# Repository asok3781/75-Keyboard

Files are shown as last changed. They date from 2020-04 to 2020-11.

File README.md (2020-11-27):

# Asok75
A 75% keyboard PCB.

A simple [acrylic case](Case) has also been designed - .dxf files are in the Case folder in the repository.

This PCB is designed to work with [QMK firmware](https://github.com/asok3781/qmk_firmware/tree/asok/keyboards/asok/asok75) (firmware is in my branch of the QMK firmware in the expected location).

A [VIA definition](asok75VIAdefinition) has also been created to be able to customise the layout of the keyboard easily.

Picture of the keyboard that I designed

Another angle

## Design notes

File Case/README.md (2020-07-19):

# Asok75 Case
A simple acrylic sandwich case for the pcb.
Layer thicknesses:
top.dxf - 3mm
tophex.dxf - 4.5mm
plate.dxf - 5mm
mid.dxf - 3mm x 2
bottom.dxf - 3mm
foot1.dxf - 3mm
foot2.dxf - 3mm
foot3.dxf - 3mm
foot4.dxf - 3mm

Use 15-16mm length and 8-9mm length, 5mm flat to flat hex standoffs and M3 screws.

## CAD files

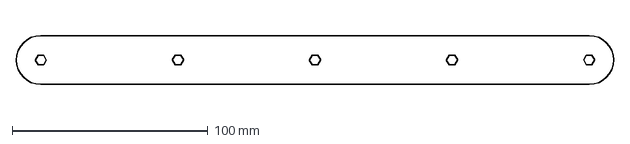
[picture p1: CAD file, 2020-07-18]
Case/foot1.dxf
305.0 x 25.0 mm

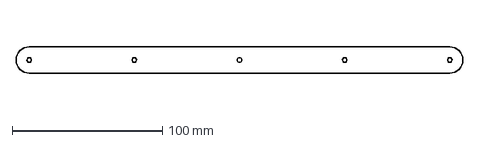
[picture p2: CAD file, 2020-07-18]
v1-pcb/Case/foot4.dxf
297.5 x 17.5 mm

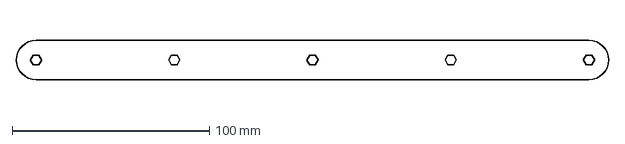
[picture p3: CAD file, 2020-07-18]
Case/foot3.dxf
300.0 x 20.0 mm

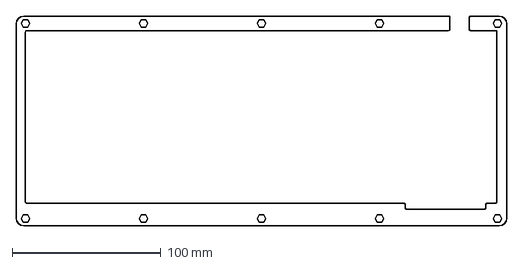
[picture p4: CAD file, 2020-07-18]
v1-pcb/Case/mid.dxf
330.0 x 141.0 mm

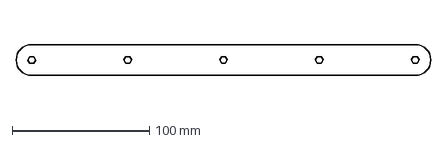
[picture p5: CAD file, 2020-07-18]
Case/foot2.dxf
302.5 x 22.5 mm

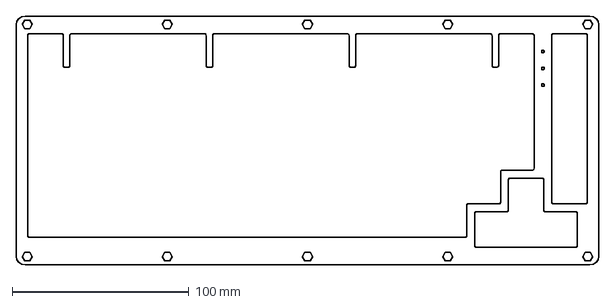
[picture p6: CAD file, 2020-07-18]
Case/tophex.dxf
330.0 x 141.0 mm

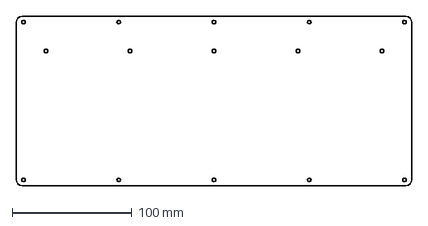
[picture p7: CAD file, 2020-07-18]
Case/bottom.dxf
330.0 x 141.0 mm

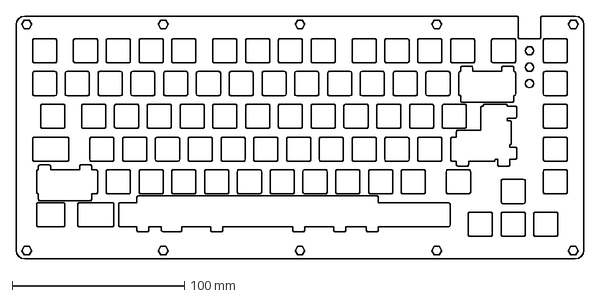
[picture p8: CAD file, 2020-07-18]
v1-pcb/Case/plate.dxf
330.0 x 141.0 mm

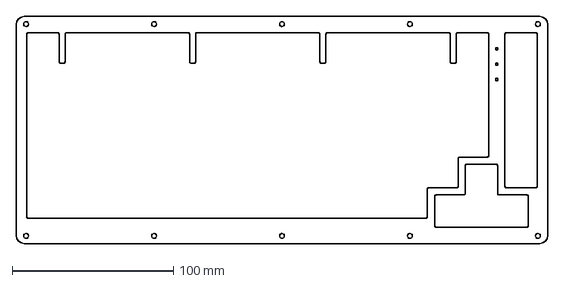
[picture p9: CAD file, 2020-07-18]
v1-pcb/Case/top.dxf
330.0 x 141.0 mm

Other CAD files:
Case/foot-0.dxf
Case/foot-1.dxf
Case/foot-2.dxf
Case/foot-3.dxf
Case/foot-4.dxf
Case/midclose.dxf
Case/midclosed.dxf
Case/topround.dxf

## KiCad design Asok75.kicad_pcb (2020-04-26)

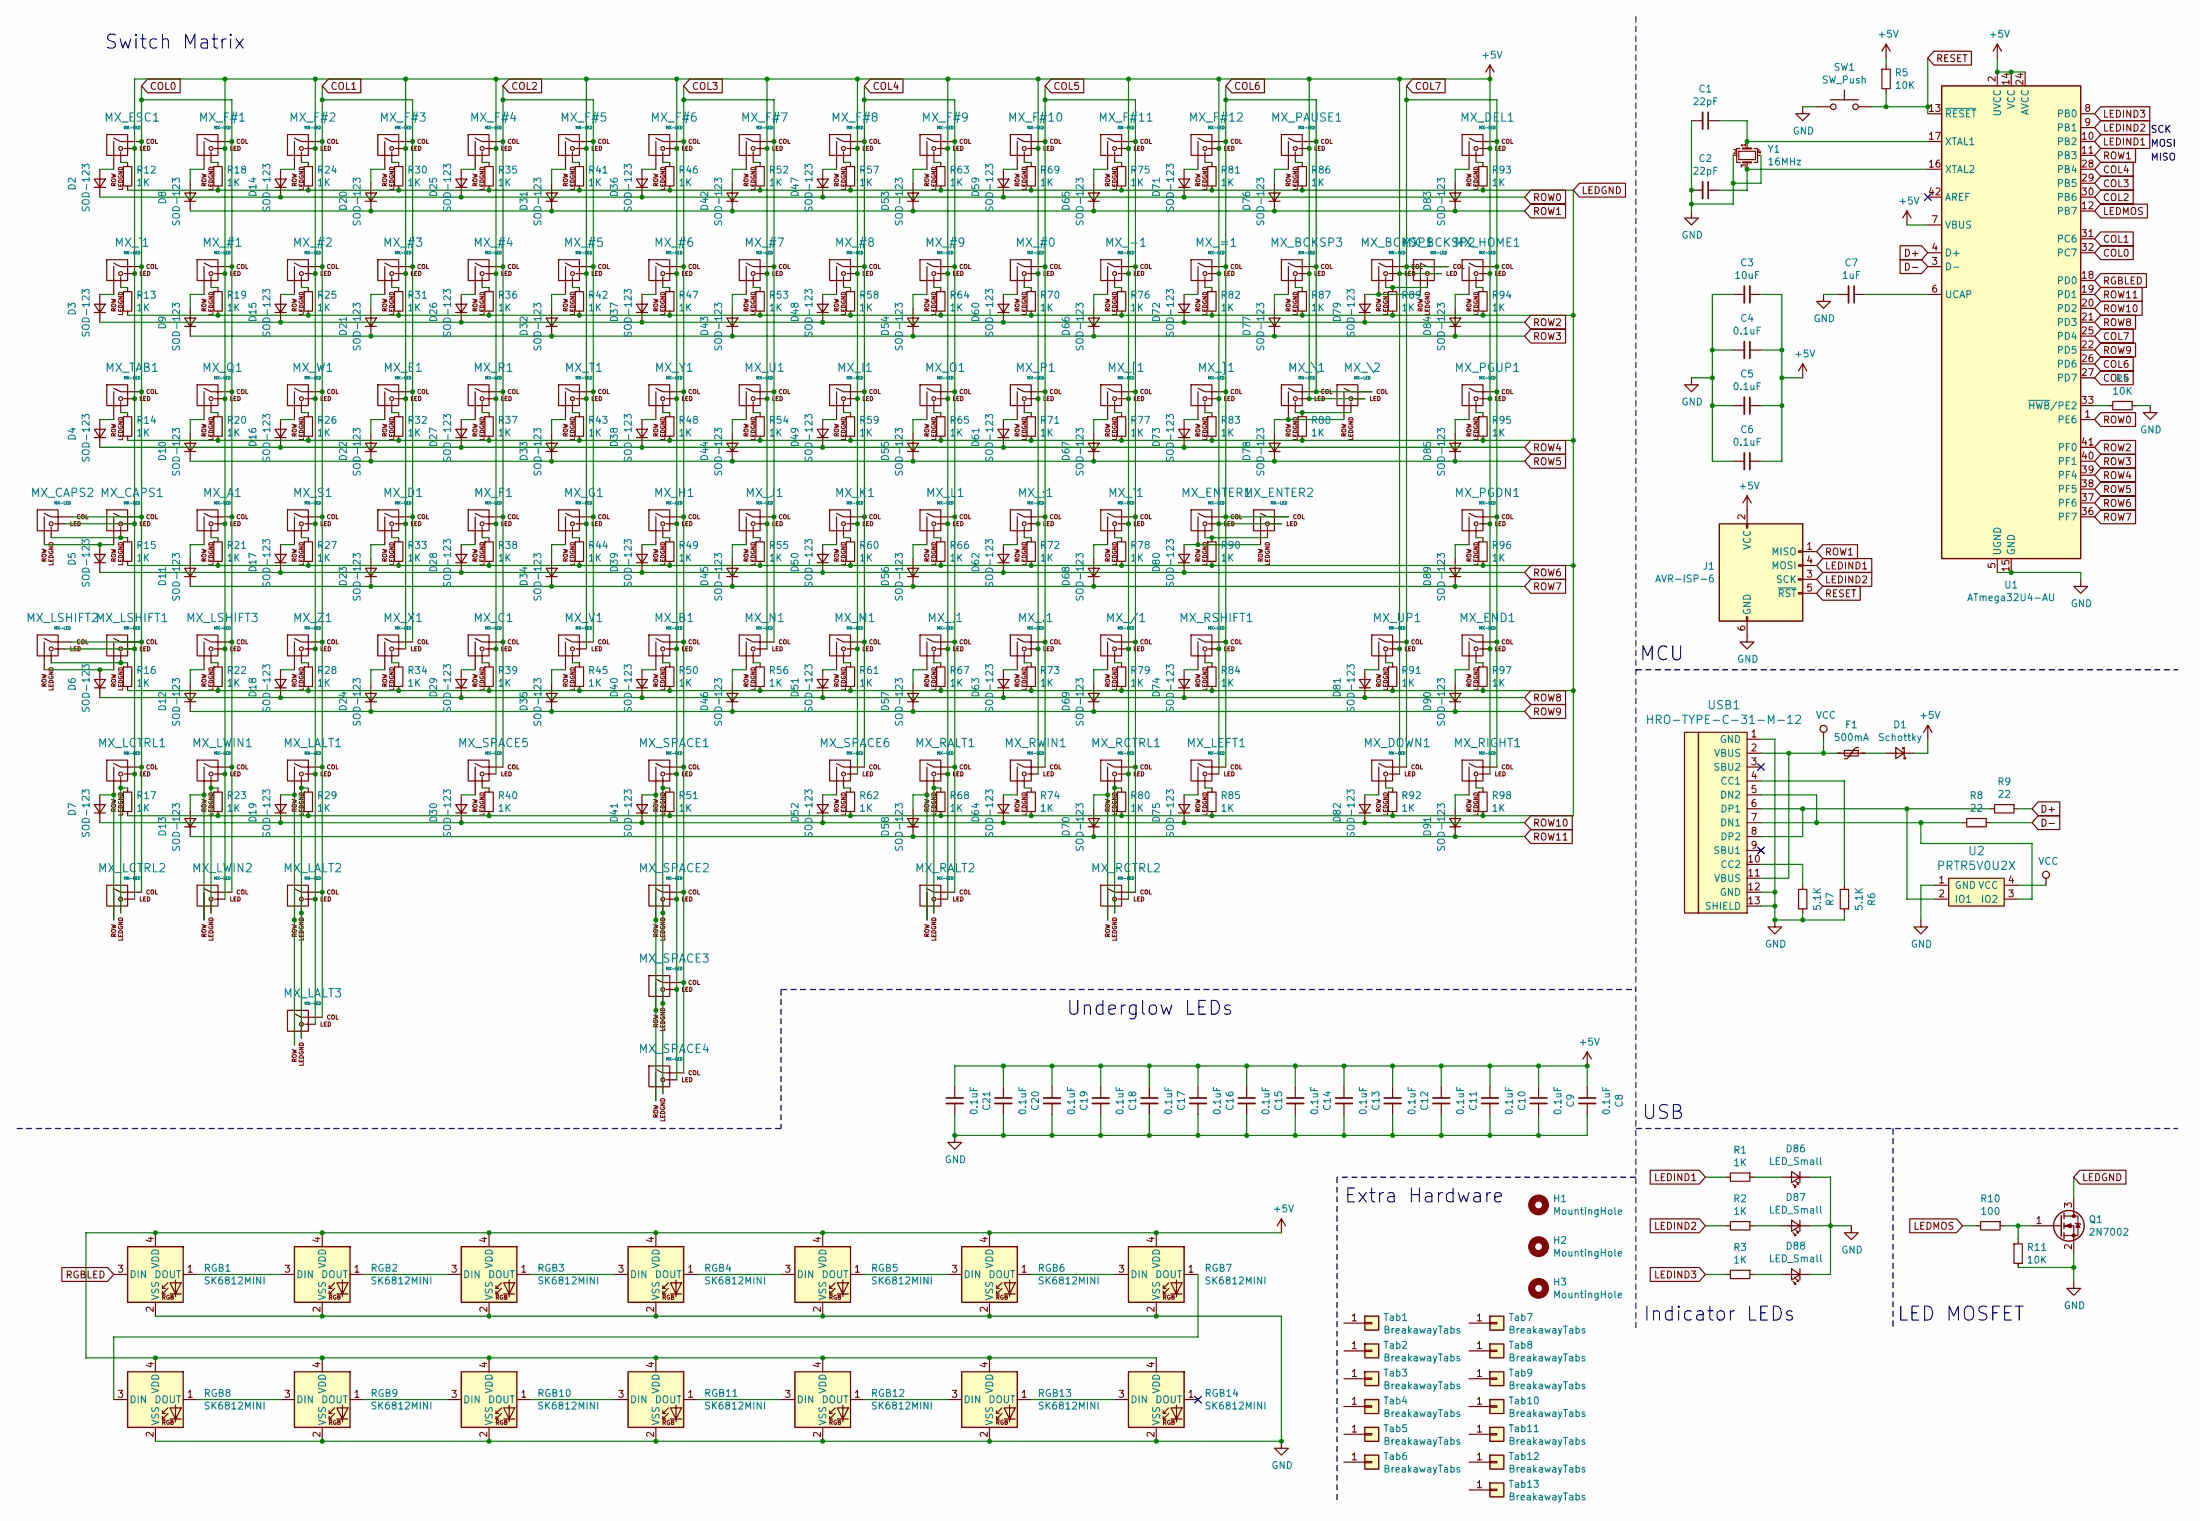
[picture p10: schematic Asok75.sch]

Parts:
C1, C2: 22pF; C_0805_2012Metric
C3: 10uF; C_0805_2012Metric
C4, C5, C6, C8, C9, C10, C11, C12, C13, C14, C15, C16, C17, C18, C19, C20, C21: 0.1uF; C_0805_2012Metric
C7: 1uF; C_0805_2012Metric
D1: Schottky; D_SOD-123-Pretty
D2, D3, D4, D5, D6, D7, D8, D9, D10, D11, D12, D13, D14, D15, D16, D17, D18, D19, D20, D21, D22, D23, D24, D25, D26, D27, D28, D29, D30, D31, D32, D33, D34, D35, D36, D37, D38, D39, D40, D41, D42, D43, D44, D45, D46, D47, D48, D49, D50, D51, D52, D53, D54, D55, D56, D57, D58, D59, D60, D61, D62, D63, D64, D65, D66, D67, D68, D69, D70, D71, D72, D73, D74, D75, D76, D77, D78, D79, D80, D81, D82, D83, D84, D85, D89, D90, D91: SOD-123; D_SOD-123-Pretty
D86, D87, D88: LED_Small; LED_D3.0mm-Pretty
F1: 500mA; Fuse_1206_3216Metric
H1, H2, H3: MountingHole; mounting
J1: AVR-ISP-6; Reset_Pretty-Mask
MX_#0, MX_#1, MX_#2, MX_#3, MX_#4, MX_#5, MX_#6, MX_#7, MX_#8, MX_#9: MX-LED; MXOnly-1U
MX_'1: MX-LED; MXOnly-1U
MX_,1: MX-LED; MXOnly-1U
MX_-1: MX-LED; MXOnly-1U
MX_.1: MX-LED; MXOnly-1U
MX_/1: MX-LED; MXOnly-1U
MX_;1: MX-LED; MXOnly-1U
MX_=1: MX-LED; MXOnly-1U
MX_A1: MX-LED; MXOnly-1U
MX_B1: MX-LED; MXOnly-1U
MX_BCKSP1: MX-LED; MXOnly-2U
MX_BCKSP2, MX_BCKSP3: MX-LED; MXOnly-1U
MX_C1: MX-LED; MXOnly-1U
MX_CAPS1: MX-LED; MXOnly-1.75U
MX_CAPS2: MX-LED; MXOnly-1.25U
MX_D1: MX-LED; MXOnly-1U
MX_DEL1: MX-LED; MXOnly-1U
MX_DOWN1: MX-LED; MXOnly-1U
MX_E1: MX-LED; MXOnly-1U
MX_END1: MX-LED; MXOnly-1U
MX_ENTER1: MX-LED; MXOnly-2.25U-ReversedStabilizers
MX_ENTER2: MX-LED; MXOnly-ISO-ROTATED-ReversedStabilizers
MX_ESC1: MX-LED; MXOnly-1U
MX_F1: MX-LED; MXOnly-1U
MX_F#1, MX_F#2, MX_F#3, MX_F#4, MX_F#5, MX_F#6, MX_F#7, MX_F#8, MX_F#9, MX_F#10, MX_F#11, MX_F#12: MX-LED; MXOnly-1U
MX_G1: MX-LED; MXOnly-1U
MX_H1: MX-LED; MXOnly-1U
MX_HOME1: MX-LED; MXOnly-1U
MX_I1: MX-LED; MXOnly-1U
MX_J1: MX-LED; MXOnly-1U
MX_K1: MX-LED; MXOnly-1U
MX_L1: MX-LED; MXOnly-1U
MX_LALT1: MX-LED; MXOnly-1.25U
MX_LALT2: MX-LED; MXOnly-1.5U-FLIPPED
MX_LALT3: MX-LED; MXOnly-1.5U
MX_LCTRL1: MX-LED; MXOnly-1.25U
MX_LCTRL2: MX-LED; MXOnly-1.5U-FLIPPED
MX_LEFT1: MX-LED; MXOnly-1U
MX_LSHIFT1: MX-LED; MXOnly-2.25U
MX_LSHIFT2: MX-LED; MXOnly-1.25U
MX_LSHIFT3: MX-LED; MXOnly-1U
MX_LWIN1: MX-LED; MXOnly-1.25U
MX_LWIN2: MX-LED; MXOnly-1U-FLIPPED
MX_M1: MX-LED; MXOnly-1U
MX_N1: MX-LED; MXOnly-1U
MX_O1: MX-LED; MXOnly-1U
MX_P1: MX-LED; MXOnly-1U
MX_PAUSE1: MX-LED; MXOnly-1U
MX_PGDN1: MX-LED; MXOnly-1U
MX_PGUP1: MX-LED; MXOnly-1U
MX_Q1: MX-LED; MXOnly-1U
MX_R1: MX-LED; MXOnly-1U
MX_RALT1: MX-LED; MXOnly-1U
MX_RALT2: MX-LED; MXOnly-1.5U
MX_RCTRL1: MX-LED; MXOnly-1U
MX_RCTRL2: MX-LED; MXOnly-1.5U
MX_RIGHT1: MX-LED; MXOnly-1U
MX_RSHIFT1: MX-LED; MXOnly-1.75U
MX_RWIN1: MX-LED; MXOnly-1U
MX_S1: MX-LED; MXOnly-1U
MX_SPACE1: MX-LED; MXOnly-6.25U-ReversedStabilizers
MX_SPACE2, MX_SPACE3: MX-LED; MXOnly-7U-ReversedStabilizers
MX_SPACE4: MX-LED; MXOnly-1.25U
MX_SPACE5: MX-LED; MXOnly-2.75U-ReversedStabilizers
MX_SPACE6: MX-LED; MXOnly-2.25U-ReversedStabilizers
MX_T1: MX-LED; MXOnly-1U
MX_TAB1: MX-LED; MXOnly-1.5U
MX_U1: MX-LED; MXOnly-1U
MX_UP1: MX-LED; MXOnly-1U
MX_V1: MX-LED; MXOnly-1U
MX_W1: MX-LED; MXOnly-1U
MX_X1: MX-LED; MXOnly-1U
MX_Y1: MX-LED; MXOnly-1U
MX_Z1: MX-LED; MXOnly-1U
MX_[1: MX-LED; MXOnly-1U
MX_\1: MX-LED; MXOnly-1.5U
MX_\2: MX-LED; MXOnly-1U
MX_]1: MX-LED; MXOnly-1U
MX_`1: MX-LED; MXOnly-1U
Q1: 2N7002; SOT-23
R1, R2, R3, R12, R13, R14, R15, R16, R17, R18, R19, R20, R21, R22, R23, R24, R25, R26, R27, R28, R29, R30, R31, R32, R33, R34, R35, R36, R37, R38, R39, R40, R41, R42, R43, R44, R45, R46, R47, R48, R49, R50, R51, R52, R53, R54, R55, R56, R57, R58, R59, R60, R61, R62, R63, R64, R65, R66, R67, R68, R69, R70, R71, R72, R73, R74, R75, R76, R77, R78, R79, R80, R81, R82, R83, R84, R85, R86, R87, R88, R89, R90, R91, R92, R93, R94, R95, R96, R97, R98: 1K; R_0805_2012Metric
R4, R5, R11: 10K; R_0805_2012Metric
R6, R7: 5.1K; R_0805_2012Metric
R8, R9: 22; R_0805_2012Metric
R10: 100; R_0805_2012Metric
RGB1, RGB2, RGB3, RGB4, RGB5, RGB6, RGB7, RGB8, RGB9, RGB10, RGB11, RGB12, RGB13, RGB14: SK6812MINI; LED_SK6812MINI_PLCC4_3.5x3.5mm_P1.75mm
SW1: SW_Push; SKQG-1155865
Tab1, Tab2, Tab3, Tab4, Tab5, Tab6, Tab7, Tab8, Tab9, Tab10, Tab11, Tab12, Tab13: BreakawayTabs; breakaway-mousebites
U1: ATmega32U4-AU; TQFP-44_10x10mm_P0.8mm
U2: PRTR5V0U2X; SOT143B
USB1: HRO-TYPE-C-31-M-12; HRO-TYPE-C-31-M-12-Assembly
Y1: 16MHz; Crystal_SMD_3225-4Pin_3.2x2.5mm

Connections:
+5V: C3.1, C4.1, C5.1, C6.1, C8.1, C9.1, C10.1, C11.1, C12.1, C13.1, C14.1, C15.1, C16.1, C17.1, C18.1, C19.1, C20.1, C21.1, D1.1 (K), J1.2 (VCC), MX_#0.3 (LED), MX_#1.3 (LED), MX_#2.3 (LED), MX_#3.3 (LED), MX_#4.3 (LED), MX_#5.3 (LED), MX_#6.3 (LED), MX_#7.3 (LED), MX_#8.3 (LED), MX_#9.3 (LED), MX_'1.3 (LED), MX_,1.3 (LED), MX_-1.3 (LED), MX_.1.3 (LED), MX_/1.3 (LED), MX_;1.3 (LED), MX_=1.3 (LED), MX_A1.3 (LED), MX_B1.3 (LED), MX_BCKSP1.3 (LED), MX_BCKSP2.3 (LED), MX_BCKSP3.3 (LED), MX_C1.3 (LED), MX_CAPS1.3 (LED), MX_CAPS2.3 (LED), MX_D1.3 (LED), MX_DEL1.3 (LED), MX_DOWN1.3 (LED), MX_E1.3 (LED), MX_END1.3 (LED), MX_ENTER1.3 (LED), MX_ENTER2.3 (LED), MX_ESC1.3 (LED), MX_F1.3 (LED), MX_F#1.3 (LED), MX_F#2.3 (LED), MX_F#3.3 (LED), MX_F#4.3 (LED), MX_F#5.3 (LED), MX_F#6.3 (LED), MX_F#7.3 (LED), MX_F#8.3 (LED), MX_F#9.3 (LED), MX_F#10.3 (LED), MX_F#11.3 (LED), MX_F#12.3 (LED), MX_G1.3 (LED), MX_H1.3 (LED), MX_HOME1.3 (LED), MX_I1.3 (LED), MX_J1.3 (LED), MX_K1.3 (LED), MX_L1.3 (LED), MX_LALT1.3 (LED), MX_LALT2.3 (LED), MX_LALT3.3 (LED), MX_LCTRL1.3 (LED), MX_LCTRL2.3 (LED), MX_LEFT1.3 (LED), MX_LSHIFT1.3 (LED), MX_LSHIFT2.3 (LED), MX_LSHIFT3.3 (LED), MX_LWIN1.3 (LED), MX_LWIN2.3 (LED), MX_M1.3 (LED), MX_N1.3 (LED), MX_O1.3 (LED), MX_P1.3 (LED), MX_PAUSE1.3 (LED), MX_PGDN1.3 (LED), MX_PGUP1.3 (LED), MX_Q1.3 (LED), MX_R1.3 (LED), MX_RALT1.3 (LED), MX_RALT2.3 (LED), MX_RCTRL1.3 (LED), MX_RCTRL2.3 (LED), MX_RIGHT1.3 (LED), MX_RSHIFT1.3 (LED), MX_RWIN1.3 (LED), MX_S1.3 (LED), MX_SPACE1.3 (LED), MX_SPACE2.3 (LED), MX_SPACE3.3 (LED), MX_SPACE4.3 (LED), MX_SPACE5.3 (LED), MX_SPACE6.3 (LED), MX_T1.3 (LED), MX_TAB1.3 (LED), MX_U1.3 (LED), MX_UP1.3 (LED), MX_V1.3 (LED), MX_W1.3 (LED), MX_X1.3 (LED), MX_Y1.3 (LED), MX_Z1.3 (LED), MX_[1.3 (LED), MX_\1.3 (LED), MX_\2.3 (LED), MX_]1.3 (LED), MX_`1.3 (LED), R5.1, RGB1.4 (VDD), RGB2.4 (VDD), RGB3.4 (VDD), RGB4.4 (VDD), RGB5.4 (VDD), RGB6.4 (VDD), RGB7.4 (VDD), RGB8.4 (VDD), RGB9.4 (VDD), RGB10.4 (VDD), RGB11.4 (VDD), RGB12.4 (VDD), RGB13.4 (VDD), RGB14.4 (VDD), U1.2 (UVCC), U1.7 (VBUS), U1.14 (VCC), U1.24 (AVCC), U1.34 (VCC), U1.44 (AVCC)
COL0: MX_#1.1 (COL), MX_A1.1 (COL), MX_CAPS1.1 (COL), MX_CAPS2.1 (COL), MX_ESC1.1 (COL), MX_F#1.1 (COL), MX_LCTRL1.1 (COL), MX_LCTRL2.1 (COL), MX_LSHIFT1.1 (COL), MX_LSHIFT2.1 (COL), MX_LSHIFT3.1 (COL), MX_LWIN1.1 (COL), MX_LWIN2.1 (COL), MX_Q1.1 (COL), MX_TAB1.1 (COL), MX_`1.1 (COL), U1.32 (PC7)
COL1: MX_#2.1 (COL), MX_#3.1 (COL), MX_D1.1 (COL), MX_E1.1 (COL), MX_F#2.1 (COL), MX_F#3.1 (COL), MX_LALT1.1 (COL), MX_LALT2.1 (COL), MX_LALT3.1 (COL), MX_S1.1 (COL), MX_W1.1 (COL), MX_X1.1 (COL), MX_Z1.1 (COL), U1.31 (PC6)
COL2: MX_#4.1 (COL), MX_#5.1 (COL), MX_C1.1 (COL), MX_F1.1 (COL), MX_F#4.1 (COL), MX_F#5.1 (COL), MX_G1.1 (COL), MX_R1.1 (COL), MX_SPACE5.1 (COL), MX_T1.1 (COL), MX_V1.1 (COL), U1.30 (PB6)
COL3: MX_#6.1 (COL), MX_#7.1 (COL), MX_B1.1 (COL), MX_F#6.1 (COL), MX_F#7.1 (COL), MX_H1.1 (COL), MX_J1.1 (COL), MX_N1.1 (COL), MX_SPACE1.1 (COL), MX_SPACE2.1 (COL), MX_SPACE3.1 (COL), MX_SPACE4.1 (COL), MX_U1.1 (COL), MX_Y1.1 (COL), U1.29 (PB5)
COL4: MX_#8.1 (COL), MX_#9.1 (COL), MX_,1.1 (COL), MX_F#8.1 (COL), MX_F#9.1 (COL), MX_I1.1 (COL), MX_K1.1 (COL), MX_L1.1 (COL), MX_M1.1 (COL), MX_O1.1 (COL), MX_RALT1.1 (COL), MX_RALT2.1 (COL), MX_SPACE6.1 (COL), U1.28 (PB4)
COL5: MX_#0.1 (COL), MX_'1.1 (COL), MX_-1.1 (COL), MX_.1.1 (COL), MX_/1.1 (COL), MX_;1.1 (COL), MX_F#10.1 (COL), MX_F#11.1 (COL), MX_P1.1 (COL), MX_RCTRL1.1 (COL), MX_RCTRL2.1 (COL), MX_RWIN1.1 (COL), MX_[1.1 (COL), U1.27 (PD7)
COL6: MX_=1.1 (COL), MX_BCKSP3.1 (COL), MX_ENTER1.1 (COL), MX_ENTER2.1 (COL), MX_F#12.1 (COL), MX_LEFT1.1 (COL), MX_PAUSE1.1 (COL), MX_RSHIFT1.1 (COL), MX_\1.1 (COL), MX_\2.1 (COL), MX_]1.1 (COL), U1.26 (PD6)
COL7: MX_BCKSP1.1 (COL), MX_BCKSP2.1 (COL), MX_DEL1.1 (COL), MX_DOWN1.1 (COL), MX_END1.1 (COL), MX_HOME1.1 (COL), MX_PGDN1.1 (COL), MX_PGUP1.1 (COL), MX_RIGHT1.1 (COL), MX_UP1.1 (COL), U1.25 (PD4)
D+: R9.1, U1.4 (D+)
D-: R8.1, U1.3 (D-)
GND: C1.2, C2.2, C3.2, C4.2, C5.2, C6.2, C7.2, C8.2, C9.2, C10.2, C11.2, C12.2, C13.2, C14.2, C15.2, C16.2, C17.2, C18.2, C19.2, C20.2, C21.2, D86.1 (K), D87.1 (K), D88.1 (K), J1.6 (GND), Q1.2 (S), R4.1, R6.1, R7.1, R11.2, RGB1.2 (VSS), RGB2.2 (VSS), RGB3.2 (VSS), RGB4.2 (VSS), RGB5.2 (VSS), RGB6.2 (VSS), RGB7.2 (VSS), RGB8.2 (VSS), RGB9.2 (VSS), RGB10.2 (VSS), RGB11.2 (VSS), RGB12.2 (VSS), RGB13.2 (VSS), RGB14.2 (VSS), SW1.1, U1.5 (UGND), U1.15 (GND), U1.23 (GND), U1.35 (GND), U1.43 (GND), U2.1 (GND), USB1.1 (GND), USB1.12 (GND), USB1.13 (SHIELD), Y1.2, Y1.4
LEDGND: Q1.3 (D), R12.2, R13.2, R14.2, R15.2, R16.2, R17.2, R18.2, R19.2, R20.2, R21.2, R22.2, R23.2, R24.2, R25.2, R26.2, R27.2, R28.2, R29.2, R30.2, R31.2, R32.2, R33.2, R34.2, R35.2, R36.2, R37.2, R38.2, R39.2, R40.2, R41.2, R42.2, R43.2, R44.2, R45.2, R46.2, R47.2, R48.2, R49.2, R50.2, R51.2, R52.2, R53.2, R54.2, R55.2, R56.2, R57.2, R58.2, R59.2, R60.2, R61.2, R62.2, R63.2, R64.2, R65.2, R66.2, R67.2, R68.2, R69.2, R70.2, R71.2, R72.2, R73.2, R74.2, R75.2, R76.2, R77.2, R78.2, R79.2, R80.2, R81.2, R82.2, R83.2, R84.2, R85.2, R86.2, R87.2, R88.2, R89.2, R90.2, R91.2, R92.2, R93.2, R94.2, R95.2, R96.2, R97.2, R98.2
LEDIND1: J1.4 (MOSI), R1.2, U1.10 (PB2)
LEDIND2: J1.3 (SCK), R2.2, U1.9 (PB1)
LEDIND3: R3.2, U1.8 (PB0)
LEDMOS: R10.2, U1.12 (PB7)
unnamed: C1.1, U1.17 (XTAL1), Y1.1
unnamed: C2.1, U1.16 (XTAL2), Y1.3
unnamed: C7.1, U1.6 (UCAP)
unnamed: D1.2 (A), F1.1
unnamed: D2.2 (A), MX_ESC1.2 (ROW)
unnamed: D3.2 (A), MX_`1.2 (ROW)
unnamed: D4.2 (A), MX_TAB1.2 (ROW)
unnamed: D5.2 (A), MX_CAPS1.2 (ROW), MX_CAPS2.2 (ROW)
unnamed: D6.2 (A), MX_LSHIFT1.2 (ROW), MX_LSHIFT2.2 (ROW)
unnamed: D7.2 (A), MX_LCTRL1.2 (ROW), MX_LCTRL2.2 (ROW)
unnamed: D8.2 (A), MX_F#1.2 (ROW)
unnamed: D9.2 (A), MX_#1.2 (ROW)
unnamed: D10.2 (A), MX_Q1.2 (ROW)
unnamed: D11.2 (A), MX_A1.2 (ROW)
unnamed: D12.2 (A), MX_LSHIFT3.2 (ROW)
unnamed: D13.2 (A), MX_LWIN1.2 (ROW), MX_LWIN2.2 (ROW)
unnamed: D14.2 (A), MX_F#2.2 (ROW)
unnamed: D15.2 (A), MX_#2.2 (ROW)
unnamed: D16.2 (A), MX_W1.2 (ROW)
unnamed: D17.2 (A), MX_S1.2 (ROW)
unnamed: D18.2 (A), MX_Z1.2 (ROW)
unnamed: D19.2 (A), MX_LALT1.2 (ROW), MX_LALT2.2 (ROW), MX_LALT3.2 (ROW)
unnamed: D20.2 (A), MX_F#3.2 (ROW)
unnamed: D21.2 (A), MX_#3.2 (ROW)
unnamed: D22.2 (A), MX_E1.2 (ROW)
unnamed: D23.2 (A), MX_D1.2 (ROW)
unnamed: D24.2 (A), MX_X1.2 (ROW)
unnamed: D25.2 (A), MX_F#4.2 (ROW)
unnamed: D26.2 (A), MX_#4.2 (ROW)
unnamed: D27.2 (A), MX_R1.2 (ROW)
unnamed: D28.2 (A), MX_F1.2 (ROW)
unnamed: D29.2 (A), MX_C1.2 (ROW)
unnamed: D30.2 (A), MX_SPACE5.2 (ROW)
unnamed: D31.2 (A), MX_F#5.2 (ROW)
unnamed: D32.2 (A), MX_#5.2 (ROW)
unnamed: D33.2 (A), MX_T1.2 (ROW)
unnamed: D34.2 (A), MX_G1.2 (ROW)
unnamed: D35.2 (A), MX_V1.2 (ROW)
unnamed: D36.2 (A), MX_F#6.2 (ROW)
unnamed: D37.2 (A), MX_#6.2 (ROW)
unnamed: D38.2 (A), MX_Y1.2 (ROW)
unnamed: D39.2 (A), MX_H1.2 (ROW)
unnamed: D40.2 (A), MX_B1.2 (ROW)
unnamed: D41.2 (A), MX_SPACE1.2 (ROW), MX_SPACE2.2 (ROW), MX_SPACE3.2 (ROW), MX_SPACE4.2 (ROW)
unnamed: D42.2 (A), MX_F#7.2 (ROW)
unnamed: D43.2 (A), MX_#7.2 (ROW)
unnamed: D44.2 (A), MX_U1.2 (ROW)
unnamed: D45.2 (A), MX_J1.2 (ROW)
unnamed: D46.2 (A), MX_N1.2 (ROW)
unnamed: D47.2 (A), MX_F#8.2 (ROW)
unnamed: D48.2 (A), MX_#8.2 (ROW)
unnamed: D49.2 (A), MX_I1.2 (ROW)
unnamed: D50.2 (A), MX_K1.2 (ROW)
unnamed: D51.2 (A), MX_M1.2 (ROW)
unnamed: D52.2 (A), MX_SPACE6.2 (ROW)
unnamed: D53.2 (A), MX_F#9.2 (ROW)
unnamed: D54.2 (A), MX_#9.2 (ROW)
unnamed: D55.2 (A), MX_O1.2 (ROW)
unnamed: D56.2 (A), MX_L1.2 (ROW)
unnamed: D57.2 (A), MX_,1.2 (ROW)
unnamed: D58.2 (A), MX_RALT1.2 (ROW), MX_RALT2.2 (ROW)
unnamed: D59.2 (A), MX_F#10.2 (ROW)
unnamed: D60.2 (A), MX_#0.2 (ROW)
unnamed: D61.2 (A), MX_P1.2 (ROW)
unnamed: D62.2 (A), MX_;1.2 (ROW)
unnamed: D63.2 (A), MX_.1.2 (ROW)
unnamed: D64.2 (A), MX_RWIN1.2 (ROW)
unnamed: D65.2 (A), MX_F#11.2 (ROW)
unnamed: D66.2 (A), MX_-1.2 (ROW)
unnamed: D67.2 (A), MX_[1.2 (ROW)
unnamed: D68.2 (A), MX_'1.2 (ROW)
unnamed: D69.2 (A), MX_/1.2 (ROW)
unnamed: D70.2 (A), MX_RCTRL1.2 (ROW), MX_RCTRL2.2 (ROW)
unnamed: D71.2 (A), MX_F#12.2 (ROW)
unnamed: D72.2 (A), MX_=1.2 (ROW)
unnamed: D73.2 (A), MX_]1.2 (ROW)
unnamed: D74.2 (A), MX_RSHIFT1.2 (ROW)
unnamed: D75.2 (A), MX_LEFT1.2 (ROW)
unnamed: D76.2 (A), MX_PAUSE1.2 (ROW)
unnamed: D77.2 (A), MX_BCKSP3.2 (ROW)
unnamed: D78.2 (A), MX_\1.2 (ROW), MX_\2.2 (ROW)
unnamed: D79.2 (A), MX_BCKSP1.2 (ROW), MX_BCKSP2.2 (ROW)
unnamed: D80.2 (A), MX_ENTER1.2 (ROW), MX_ENTER2.2 (ROW)
unnamed: D81.2 (A), MX_UP1.2 (ROW)
unnamed: D82.2 (A), MX_DOWN1.2 (ROW)
unnamed: D83.2 (A), MX_DEL1.2 (ROW)
unnamed: D84.2 (A), MX_HOME1.2 (ROW)
unnamed: D85.2 (A), MX_PGUP1.2 (ROW)
unnamed: D86.2 (A), R1.1
unnamed: D87.2 (A), R2.1
unnamed: D88.2 (A), R3.1
unnamed: D89.2 (A), MX_PGDN1.2 (ROW)
unnamed: D90.2 (A), MX_END1.2 (ROW)
unnamed: D91.2 (A), MX_RIGHT1.2 (ROW)
unnamed: MX_#0.4 (LEDGND), R70.1
unnamed: MX_#1.4 (LEDGND), R19.1
unnamed: MX_#2.4 (LEDGND), R25.1
unnamed: MX_#3.4 (LEDGND), R31.1
unnamed: MX_#4.4 (LEDGND), R36.1
unnamed: MX_#5.4 (LEDGND), R42.1
unnamed: MX_#6.4 (LEDGND), R47.1
unnamed: MX_#7.4 (LEDGND), R53.1
unnamed: MX_#8.4 (LEDGND), R58.1
unnamed: MX_#9.4 (LEDGND), R64.1
unnamed: MX_'1.4 (LEDGND), R78.1
unnamed: MX_,1.4 (LEDGND), R67.1
unnamed: MX_-1.4 (LEDGND), R76.1
unnamed: MX_.1.4 (LEDGND), R73.1
unnamed: MX_/1.4 (LEDGND), R79.1
unnamed: MX_;1.4 (LEDGND), R72.1
unnamed: MX_=1.4 (LEDGND), R82.1
unnamed: MX_A1.4 (LEDGND), R21.1
unnamed: MX_B1.4 (LEDGND), R50.1
unnamed: MX_BCKSP1.4 (LEDGND), MX_BCKSP2.4 (LEDGND), R89.1
unnamed: MX_BCKSP3.4 (LEDGND), R87.1
unnamed: MX_C1.4 (LEDGND), R39.1
unnamed: MX_CAPS1.4 (LEDGND), MX_CAPS2.4 (LEDGND), R15.1
unnamed: MX_D1.4 (LEDGND), R33.1
unnamed: MX_DEL1.4 (LEDGND), R93.1
unnamed: MX_DOWN1.4 (LEDGND), R92.1
unnamed: MX_E1.4 (LEDGND), R32.1
unnamed: MX_END1.4 (LEDGND), R97.1
unnamed: MX_ENTER1.4 (LEDGND), MX_ENTER2.4 (LEDGND), R90.1
unnamed: MX_ESC1.4 (LEDGND), R12.1
unnamed: MX_F1.4 (LEDGND), R38.1
unnamed: MX_F#1.4 (LEDGND), R18.1
unnamed: MX_F#2.4 (LEDGND), R24.1
unnamed: MX_F#3.4 (LEDGND), R30.1
unnamed: MX_F#4.4 (LEDGND), R35.1
unnamed: MX_F#5.4 (LEDGND), R41.1
unnamed: MX_F#6.4 (LEDGND), R46.1
unnamed: MX_F#7.4 (LEDGND), R52.1
unnamed: MX_F#8.4 (LEDGND), R57.1
unnamed: MX_F#9.4 (LEDGND), R63.1
unnamed: MX_F#10.4 (LEDGND), R69.1
unnamed: MX_F#11.4 (LEDGND), R75.1
unnamed: MX_F#12.4 (LEDGND), R81.1
unnamed: MX_G1.4 (LEDGND), R44.1
unnamed: MX_H1.4 (LEDGND), R49.1
unnamed: MX_HOME1.4 (LEDGND), R94.1
unnamed: MX_I1.4 (LEDGND), R59.1
unnamed: MX_J1.4 (LEDGND), R55.1
unnamed: MX_K1.4 (LEDGND), R60.1
unnamed: MX_L1.4 (LEDGND), R66.1
unnamed: MX_LALT1.4 (LEDGND), MX_LALT2.4 (LEDGND), MX_LALT3.4 (LEDGND), R29.1
unnamed: MX_LCTRL1.4 (LEDGND), MX_LCTRL2.4 (LEDGND), R17.1
unnamed: MX_LEFT1.4 (LEDGND), R85.1
unnamed: MX_LSHIFT1.4 (LEDGND), MX_LSHIFT2.4 (LEDGND), R16.1
unnamed: MX_LSHIFT3.4 (LEDGND), R22.1
unnamed: MX_LWIN1.4 (LEDGND), MX_LWIN2.4 (LEDGND), R23.1
unnamed: MX_M1.4 (LEDGND), R61.1
unnamed: MX_N1.4 (LEDGND), R56.1
unnamed: MX_O1.4 (LEDGND), R65.1
unnamed: MX_P1.4 (LEDGND), R71.1
unnamed: MX_PAUSE1.4 (LEDGND), R86.1
unnamed: MX_PGDN1.4 (LEDGND), R96.1
unnamed: MX_PGUP1.4 (LEDGND), R95.1
unnamed: MX_Q1.4 (LEDGND), R20.1
unnamed: MX_R1.4 (LEDGND), R37.1
unnamed: MX_RALT1.4 (LEDGND), MX_RALT2.4 (LEDGND), R68.1
unnamed: MX_RCTRL1.4 (LEDGND), MX_RCTRL2.4 (LEDGND), R80.1
unnamed: MX_RIGHT1.4 (LEDGND), R98.1
unnamed: MX_RSHIFT1.4 (LEDGND), R84.1
unnamed: MX_RWIN1.4 (LEDGND), R74.1
unnamed: MX_S1.4 (LEDGND), R27.1
unnamed: MX_SPACE1.4 (LEDGND), MX_SPACE2.4 (LEDGND), MX_SPACE3.4 (LEDGND), MX_SPACE4.4 (LEDGND), R51.1
unnamed: MX_SPACE5.4 (LEDGND), R40.1
unnamed: MX_SPACE6.4 (LEDGND), R62.1
unnamed: MX_T1.4 (LEDGND), R43.1
unnamed: MX_TAB1.4 (LEDGND), R14.1
unnamed: MX_U1.4 (LEDGND), R54.1
unnamed: MX_UP1.4 (LEDGND), R91.1
unnamed: MX_V1.4 (LEDGND), R45.1
unnamed: MX_W1.4 (LEDGND), R26.1
unnamed: MX_X1.4 (LEDGND), R34.1
unnamed: MX_Y1.4 (LEDGND), R48.1
unnamed: MX_Z1.4 (LEDGND), R28.1
unnamed: MX_[1.4 (LEDGND), R77.1
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

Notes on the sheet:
MCU
USB
Indicator LEDs
Switch Matrix
LED MOSFET
Underglow LEDs
SCK
MOSI
MISO
Extra Hardware

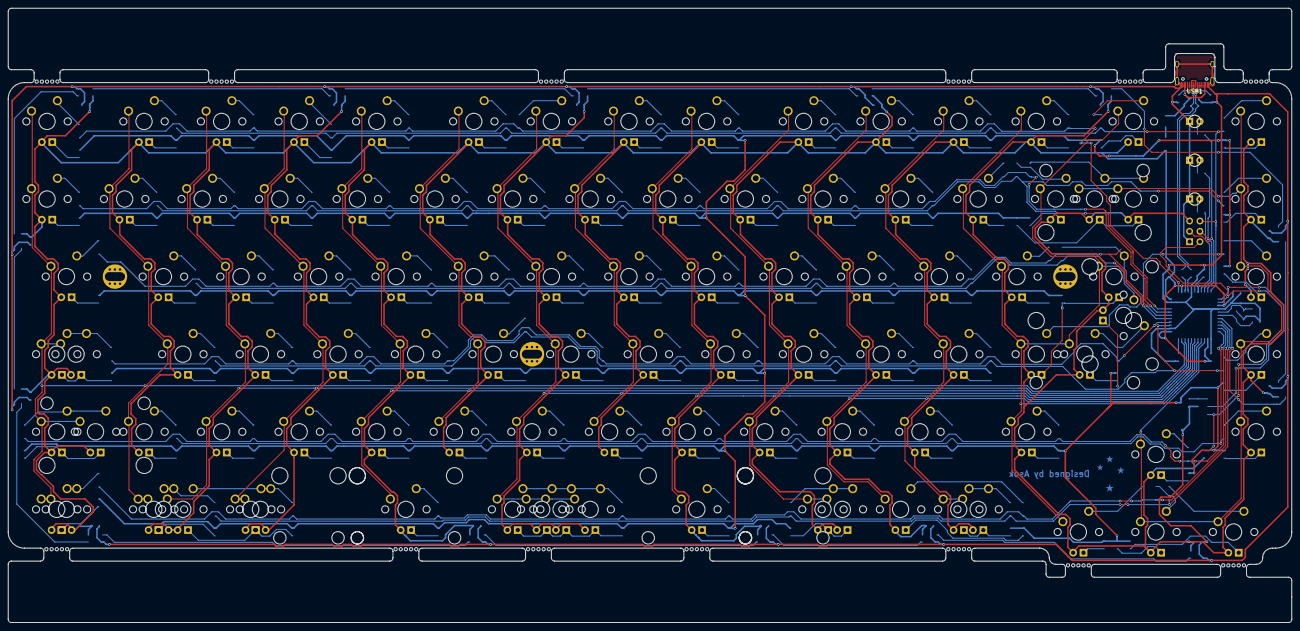
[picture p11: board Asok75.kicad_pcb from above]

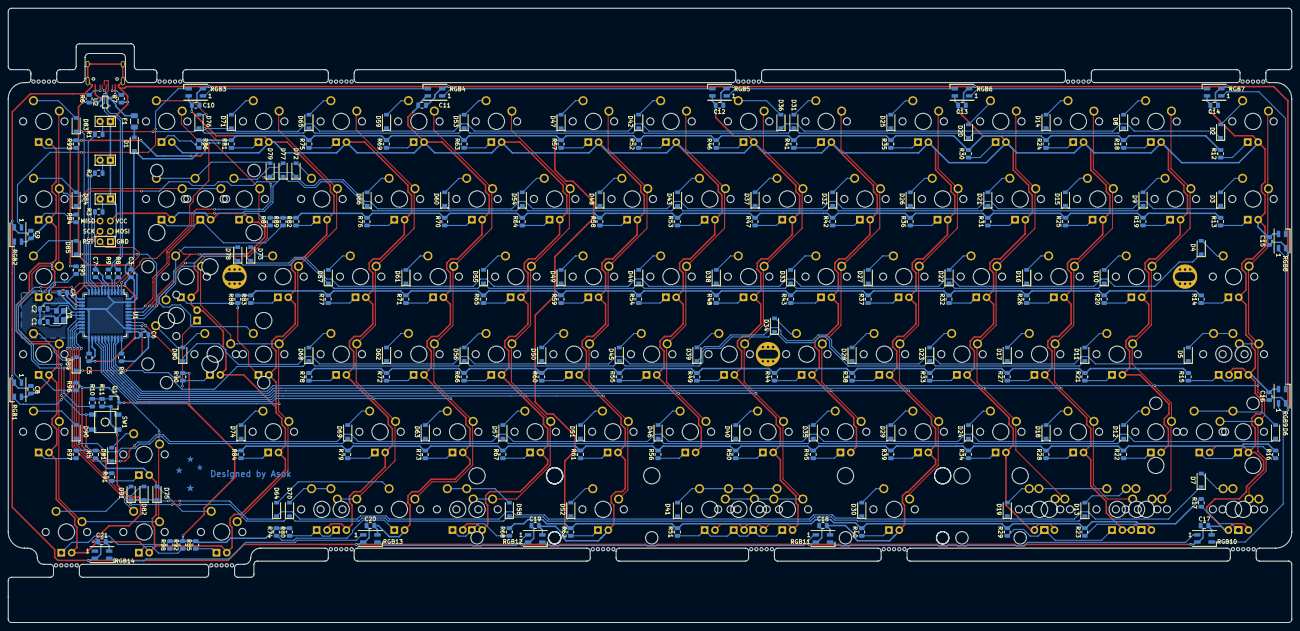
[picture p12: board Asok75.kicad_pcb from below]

Board: 2 copper layers, 315.1 x 150.8 mm, 349 parts (228 on the bottom side), 232 nets.

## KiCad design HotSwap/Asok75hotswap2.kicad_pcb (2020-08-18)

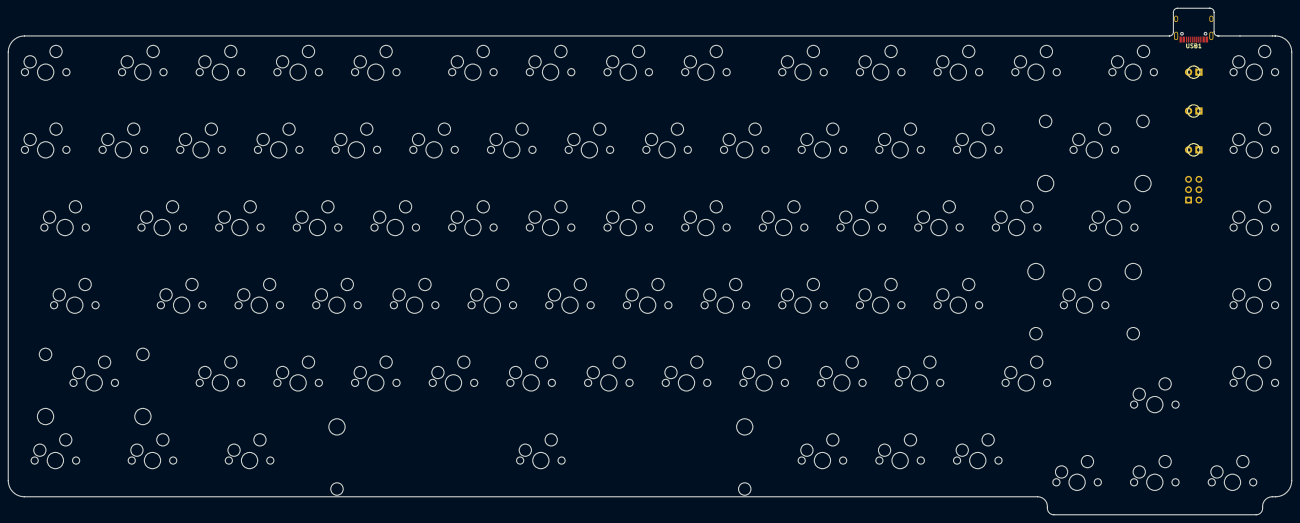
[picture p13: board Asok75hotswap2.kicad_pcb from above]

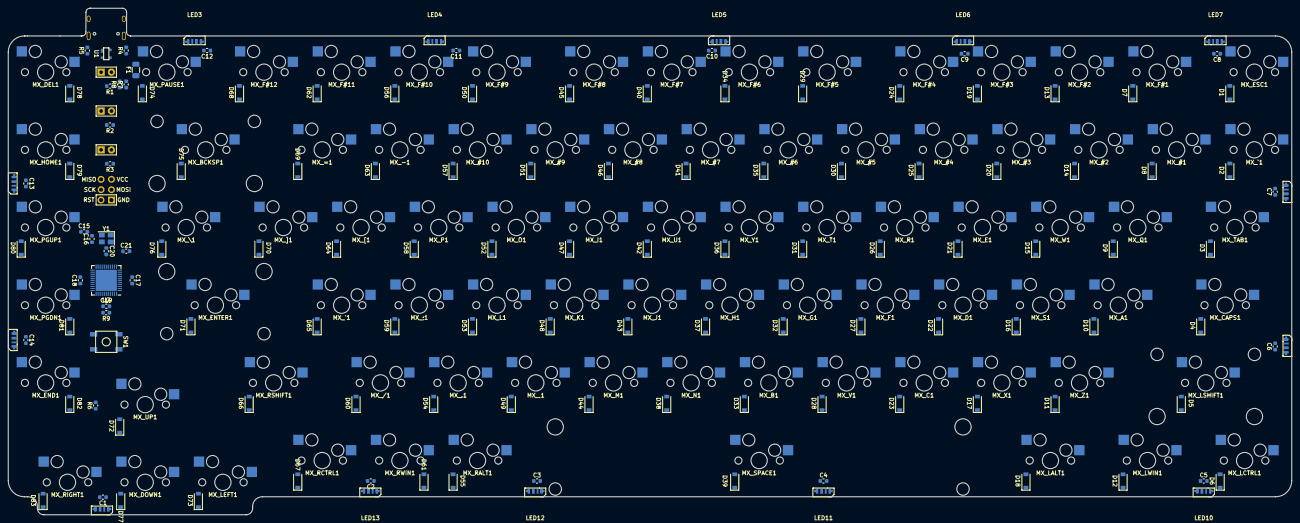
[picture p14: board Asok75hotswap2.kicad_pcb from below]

Board: 2 copper layers, 314.8 x 124.2 mm, 233 parts (133 on the bottom side), 137 nets, no tracks yet.

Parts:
C1, C2, C3, C4, C5, C6, C7, C8, C9, C10, C11, C12, C13, C14, C18, C19, C20: 0.1uF; C_0603_1608Metric
C15, C16: 22pF; C_0603_1608Metric
C17: 10uF; C_0603_1608Metric
C21: 1uF; C_0603_1608Metric
D1, D2, D3, D4, D5, D6, D7, D8, D9, D10, D11, D12, D13, D14, D15, D16, D17, D18, D19, D20, D21, D22, D23, D24, D25, D26, D27, D28, D29, D30, D31, D32, D33, D34, D35, D36, D37, D38, D39, D40, D41, D42, D43, D44, D45, D46, D47, D48, D49, D50, D51, D52, D53, D54, D55, D56, D57, D58, D59, D60, D61, D62, D63, D64, D65, D66, D67, D68, D69, D70, D71, D72, D73, D74, D75, D76, D77, D78, D79, D80, D81, D82, D83: SOD-123; D_SOD-123-Pretty
D84, D85, D86: LED_Small; LED_D3.0mm-Pretty
F1: 500mA; Fuse_1206_3216Metric
J1: AVR-ISP-6; Reset_Pretty-Mask
LED1, LED2, LED3, LED4, LED5, LED6, LED7, LED8, LED9, LED10, LED11, LED12, LED13, LED14: SK6812-SIDEA-4020
MX_#1, MX_#2, MX_#3, MX_#4, MX_#5, MX_#6, MX_#7, MX_#8, MX_#9, MX_#10: MX-LED; MXOnly-1U-Hotswap
MX_'1: MX-LED; MXOnly-1U-Hotswap
MX_,1: MX-LED; MXOnly-1U-Hotswap
MX_-1: MX-LED; MXOnly-1U-Hotswap
MX_.1: MX-LED; MXOnly-1U-Hotswap
MX_/1: MX-LED; MXOnly-1U-Hotswap
MX_;1: MX-LED; MXOnly-1U-Hotswap
MX_=1: MX-LED; MXOnly-1U-Hotswap
MX_A1: MX-LED; MXOnly-1U-Hotswap
MX_B1: MX-LED; MXOnly-1U-Hotswap
MX_BCKSP1: MX-LED; MXOnly-2U-Hotswap
MX_C1: MX-LED; MXOnly-1U-Hotswap
MX_CAPS1: MX-LED; MXOnly-1.75U-Hotswap
MX_D1: MX-LED; MXOnly-1U-Hotswap
MX_DEL1: MX-LED; MXOnly-1U-Hotswap
MX_DOWN1: MX-LED; MXOnly-1U-Hotswap
MX_E1: MX-LED; MXOnly-1U-Hotswap
MX_END1: MX-LED; MXOnly-1U-Hotswap
MX_ENTER1: MX-LED; MXOnly-2.25U-Hotswap-ReversedStabilizers
MX_ESC1: MX-LED; MXOnly-1U-Hotswap
MX_F1: MX-LED; MXOnly-1U-Hotswap
MX_F#1, MX_F#2, MX_F#3, MX_F#4, MX_F#5, MX_F#6, MX_F#7, MX_F#8, MX_F#9, MX_F#10, MX_F#11, MX_F#12: MX-LED; MXOnly-1U-Hotswap
MX_G1: MX-LED; MXOnly-1U-Hotswap
MX_H1: MX-LED; MXOnly-1U-Hotswap
MX_HOME1: MX-LED; MXOnly-1U-Hotswap
MX_I1: MX-LED; MXOnly-1U-Hotswap
MX_J1: MX-LED; MXOnly-1U-Hotswap
MX_K1: MX-LED; MXOnly-1U-Hotswap
MX_L1: MX-LED; MXOnly-1U-Hotswap
MX_LALT1: MX-LED; MXOnly-1.25U-Hotswap
MX_LCTRL1: MX-LED; MXOnly-1.25U-Hotswap
MX_LEFT1: MX-LED; MXOnly-1U-Hotswap
MX_LSHIFT1: MX-LED; MXOnly-2.25U-Hotswap
MX_LWIN1: MX-LED; MXOnly-1.25U-Hotswap
MX_M1: MX-LED; MXOnly-1U-Hotswap
MX_N1: MX-LED; MXOnly-1U-Hotswap
MX_O1: MX-LED; MXOnly-1U-Hotswap
MX_P1: MX-LED; MXOnly-1U-Hotswap
MX_PAUSE1: MX-LED; MXOnly-1U-Hotswap
MX_PGDN1: MX-LED; MXOnly-1U-Hotswap
MX_PGUP1: MX-LED; MXOnly-1U-Hotswap
MX_Q1: MX-LED; MXOnly-1U-Hotswap
MX_R1: MX-LED; MXOnly-1U-Hotswap
MX_RALT1: MX-LED; MXOnly-1U-Hotswap
MX_RCTRL1: MX-LED; MXOnly-1U-Hotswap
MX_RIGHT1: MX-LED; MXOnly-1U-Hotswap
MX_RSHIFT1: MX-LED; MXOnly-1.75U-Hotswap
MX_RWIN1: MX-LED; MXOnly-1U-Hotswap
MX_S1: MX-LED; MXOnly-1U-Hotswap
MX_SPACE1: MX-LED; MXOnly-6.25U-Hotswap-ReversedStabilizers
MX_T1: MX-LED; MXOnly-1U-Hotswap
MX_TAB1: MX-LED; MXOnly-1.5U-Hotswap
MX_U1: MX-LED; MXOnly-1U-Hotswap
MX_UP1: MX-LED; MXOnly-1U-Hotswap
MX_V1: MX-LED; MXOnly-1U-Hotswap
MX_W1: MX-LED; MXOnly-1U-Hotswap
MX_X1: MX-LED; MXOnly-1U-Hotswap
MX_Y1: MX-LED; MXOnly-1U-Hotswap
MX_Z1: MX-LED; MXOnly-1U-Hotswap
MX_[1: MX-LED; MXOnly-1U-Hotswap
MX_\1: MX-LED; MXOnly-1.5U-Hotswap
MX_]1: MX-LED; MXOnly-1U-Hotswap
MX_`1: MX-LED; MXOnly-1U-Hotswap
R1, R2, R3: 1K; R_0603_1608Metric
R4, R5: 5.1K; R_0603_1608Metric
R6, R9: 10K; R_0603_1608Metric
R7, R8: 22; R_0603_1608Metric
SW1: SW_Push; SKQG-1155865
Tab1, Tab2, Tab3, Tab4, Tab5, Tab6, Tab7, Tab8, Tab9, Tab10, Tab11, Tab12, Tab13: BreakawayTabs; breakaway-mousebites
U1: PRTR5V0U2X; SOT143B
U2: ATmega32U4-MU; QFN-44-1EP_7x7mm_P0.5mm_EP5.2x5.2mm
USB1: HRO-TYPE-C-31-M-12; HRO-TYPE-C-31-M-12-Assembly
Y1: 16MHz; Crystal_SMD_3225-4Pin_3.2x2.5mm

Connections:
+5V: C1.1, C2.1, C3.1, C4.1, C5.1, C6.1, C7.1, C8.1, C9.1, C10.1, C11.1, C12.1, C13.1, C14.1, C17.1, C18.1, C19.1, C20.1, F1.1, J1.2, LED1.2, LED2.2, LED3.2, LED4.2, LED5.2, LED6.2, LED7.2, LED8.2, LED9.2, LED10.2, LED11.2, LED12.2, LED13.2, LED14.2, R6.1, U2.2, U2.7, U2.14, U2.24, U2.34, U2.44
COL0: MX_#1.1, MX_A1.1, MX_CAPS1.1, MX_ESC1.1, MX_F#1.1, MX_LCTRL1.1, MX_LSHIFT1.1, MX_LWIN1.1, MX_Q1.1, MX_TAB1.1, MX_Z1.1, MX_`1.1, U2.32
COL1: MX_#2.1, MX_#3.1, MX_C1.1, MX_D1.1, MX_E1.1, MX_F#2.1, MX_F#3.1, MX_LALT1.1, MX_S1.1, MX_W1.1, MX_X1.1, U2.31
COL2: MX_#4.1, MX_#5.1, MX_B1.1, MX_F1.1, MX_F#4.1, MX_F#5.1, MX_G1.1, MX_R1.1, MX_T1.1, MX_V1.1, U2.30
COL3: MX_#6.1, MX_#7.1, MX_F#6.1, MX_F#7.1, MX_H1.1, MX_J1.1, MX_M1.1, MX_N1.1, MX_SPACE1.1, MX_U1.1, MX_Y1.1, U2.29
COL4: MX_#8.1, MX_#9.1, MX_,1.1, MX_.1.1, MX_F#8.1, MX_F#9.1, MX_I1.1, MX_K1.1, MX_L1.1, MX_O1.1, MX_RALT1.1, U2.28
COL5: MX_#10.1, MX_'1.1, MX_-1.1, MX_/1.1, MX_;1.1, MX_F#10.1, MX_F#11.1, MX_P1.1, MX_RCTRL1.1, MX_RSHIFT1.1, MX_RWIN1.1, MX_[1.1, U2.27
COL6: MX_=1.1, MX_BCKSP1.1, MX_DOWN1.1, MX_ENTER1.1, MX_F#12.1, MX_LEFT1.1, MX_PAUSE1.1, MX_UP1.1, MX_\1.1, MX_]1.1, U2.26
COL7: MX_DEL1.1, MX_END1.1, MX_HOME1.1, MX_PGDN1.1, MX_PGUP1.1, MX_RIGHT1.1, U2.25
D+: R8.1, U2.4
D-: R7.1, U2.3
GND: C1.2, C2.2, C3.2, C4.2, C5.2, C6.2, C7.2, C8.2, C9.2, C10.2, C11.2, C12.2, C13.2, C14.2, C15.2, C16.2, C17.2, C18.2, C19.2, C20.2, C21.2, D84.1, D85.1, D86.1, J1.6, LED1.4, LED2.4, LED3.4, LED4.4, LED5.4, LED6.4, LED7.4, LED8.4, LED9.4, LED10.4, LED11.4, LED12.4, LED13.4, LED14.4, R4.1, R5.1, R9.1, SW1.1, U1.1, U2.5, U2.15, U2.23, U2.35, U2.43, U2.45, USB1.1, USB1.12, USB1.13, Y1.2, Y1.4
LEDIND1: J1.4, R1.2, U2.10
LEDIND2: J1.3, R2.2, U2.9
LEDIND3: R3.2, U2.8
unnamed: C15.1, U2.17, Y1.1
unnamed: C16.1, U2.16, Y1.3
unnamed: C21.1, U2.6
unnamed: D1.2, MX_ESC1.2
unnamed: D2.2, MX_`1.2
unnamed: D3.2, MX_TAB1.2
unnamed: D4.2, MX_CAPS1.2
unnamed: D5.2, MX_LSHIFT1.2
unnamed: D6.2, MX_LCTRL1.2
unnamed: D7.2, MX_F#1.2
unnamed: D8.2, MX_#1.2
unnamed: D9.2, MX_Q1.2
unnamed: D10.2, MX_A1.2
unnamed: D11.2, MX_Z1.2
unnamed: D12.2, MX_LWIN1.2
unnamed: D13.2, MX_F#2.2
unnamed: D14.2, MX_#2.2
unnamed: D15.2, MX_W1.2
unnamed: D16.2, MX_S1.2
unnamed: D17.2, MX_X1.2
unnamed: D18.2, MX_LALT1.2
unnamed: D19.2, MX_F#3.2
unnamed: D20.2, MX_#3.2
unnamed: D21.2, MX_E1.2
unnamed: D22.2, MX_D1.2
unnamed: D23.2, MX_C1.2
unnamed: D24.2, MX_F#4.2
unnamed: D25.2, MX_#4.2
unnamed: D26.2, MX_R1.2
unnamed: D27.2, MX_F1.2
unnamed: D28.2, MX_V1.2
unnamed: D29.2, MX_F#5.2
unnamed: D30.2, MX_#5.2
unnamed: D31.2, MX_T1.2
unnamed: D32.2, MX_G1.2
unnamed: D33.2, MX_B1.2
unnamed: D34.2, MX_F#6.2
unnamed: D35.2, MX_#6.2
unnamed: D36.2, MX_Y1.2
unnamed: D37.2, MX_H1.2
unnamed: D38.2, MX_N1.2
unnamed: D39.2, MX_SPACE1.2
unnamed: D40.2, MX_F#7.2
unnamed: D41.2, MX_#7.2
unnamed: D42.2, MX_U1.2
unnamed: D43.2, MX_J1.2
unnamed: D44.2, MX_M1.2
unnamed: D45.2, MX_F#8.2
unnamed: D46.2, MX_#8.2
unnamed: D47.2, MX_I1.2
unnamed: D48.2, MX_K1.2
unnamed: D49.2, MX_,1.2
unnamed: D50.2, MX_F#9.2
unnamed: D51.2, MX_#9.2
unnamed: D52.2, MX_O1.2
unnamed: D53.2, MX_L1.2
unnamed: D54.2, MX_.1.2
unnamed: D55.2, MX_RALT1.2
unnamed: D56.2, MX_F#10.2
unnamed: D57.2, MX_#10.2
unnamed: D58.2, MX_P1.2
unnamed: D59.2, MX_;1.2
unnamed: D60.2, MX_/1.2
unnamed: D61.2, MX_RWIN1.2
unnamed: D62.2, MX_F#11.2
unnamed: D63.2, MX_-1.2
unnamed: D64.2, MX_[1.2
unnamed: D65.2, MX_'1.2
unnamed: D66.2, MX_RSHIFT1.2
unnamed: D67.2, MX_RCTRL1.2
unnamed: D68.2, MX_F#12.2
unnamed: D69.2, MX_=1.2
unnamed: D70.2, MX_]1.2
unnamed: D71.2, MX_ENTER1.2
unnamed: D72.2, MX_UP1.2
unnamed: D73.2, MX_LEFT1.2
unnamed: D74.2, MX_PAUSE1.2
unnamed: D75.2, MX_BCKSP1.2
unnamed: D76.2, MX_\1.2
unnamed: D77.2, MX_DOWN1.2
unnamed: D78.2, MX_DEL1.2
unnamed: D79.2, MX_HOME1.2
unnamed: D80.2, MX_PGUP1.2
unnamed: D81.2, MX_PGDN1.2
unnamed: D82.2, MX_END1.2
unnamed: D83.2, MX_RIGHT1.2
unnamed: D84.2, R1.1
unnamed: D85.2, R2.1
unnamed: D86.2, R3.1
unnamed: LED1.3, LED3.1
unnamed: LED2.3, LED4.1
unnamed: LED3.3, LED5.1
unnamed: LED4.3, LED6.1
unnamed: LED5.3, LED7.1
unnamed: LED6.3, LED8.1
unnamed: LED7.3, LED9.1
unnamed: LED8.3, LED10.1
unnamed: LED10.3, LED12.1
unnamed: LED9.3, LED11.1
unnamed: LED11.3, LED13.1
unnamed: LED12.3, LED14.1
unnamed: LED2.1, LED13.3
unnamed: R4.2, USB1.10
unnamed: R5.2, USB1.4
unnamed: R7.2, U1.3, USB1.5, USB1.7
unnamed: R8.2, U1.2, USB1.6, USB1.8
unnamed: R9.2, U2.33
RESET: J1.5, R6.2, SW1.2, U2.13
RGBLED: LED1.1, U2.18
ROW0: D1.1, D13.1, D24.1, D34.1, D45.1, D56.1, D68.1, D78.1, U2.1
ROW1: D7.1, D19.1, D29.1, D40.1, D50.1, D62.1, D74.1, J1.1, U2.11
ROW2: D2.1, D14.1, D25.1, D35.1, D46.1, D57.1, D69.1, D79.1, U2.41
ROW3: D8.1, D20.1, D30.1, D41.1, D51.1, D63.1, D75.1, U2.40
ROW4: D3.1, D15.1, D26.1, D36.1, D47.1, D58.1, D70.1, D80.1, U2.39
ROW5: D9.1, D21.1, D31.1, D42.1, D52.1, D64.1, D76.1, U2.38
ROW6: D4.1, D16.1, D27.1, D37.1, D48.1, D59.1, D71.1, D81.1, U2.37
ROW7: D10.1, D22.1, D32.1, D43.1, D53.1, D65.1, U2.36
ROW8: D5.1, D17.1, D28.1, D38.1, D49.1, D60.1, D72.1, D82.1, U2.21
ROW9: D11.1, D23.1, D33.1, D44.1, D54.1, D66.1, U2.22
ROW10: D6.1, D18.1, D39.1, D61.1, D73.1, D83.1, U2.20
ROW11: D12.1, D55.1, D67.1, D77.1, U2.19
VCC: F1.2, U1.4, USB1.2, USB1.11

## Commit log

2020-03-29 Initialised project
    [75-PCB.kicad_pcb, 75-PCB.sch]
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2020-03-29 Finished MCU schematic
    [75-PCB.sch]
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2020-03-29 Finished USB schematic
    [75-PCB.sch]
2020-03-29 Finished placing switch symbols
    [75-PCB.sch]
2020-03-29 Finished columns in switch matrix
    [75-PCB.sch]
2020-03-30 Finished switch matrix schematic
    [75-PCB.sch]
2020-03-30 Added Schottky diode
    [75-PCB.sch]
2020-03-30 Changed switches to support LEDs
    [75-PCB.sch]
2020-03-31 Changed MCU from ATmega32U4 to AT90USB1286 for more pins
    [75-PCB.sch]
2020-03-31 Added ISP to schematic
    [75-PCB.sch]
2020-03-31 Changed layout of switch matrix in schematic
    [75-PCB.sch]
2020-04-01 Created copy of schematic for hot-swap implementation, added diodes and an extra switch symbol for split backspace support
    [75-PCB-Hot-Swap.sch, 75-PCB.sch]
2020-04-01 Added switch for split right shift support
    [75-PCB.sch]
2020-04-02 Added switches for multiple layouts
    [75-PCB.sch]
2020-04-02 Added switches for modifiers for 7U spacebar
    [75-PCB.sch]
2020-04-02 Finished LED backlight matrix
    [75-PCB.sch]
2020-04-04 Added submodule for RGB LEDs
    [75-PCB.sch]
2020-04-04 Added Underglow LEDs
    [75-PCB.sch]
2020-04-06 Added switches for JIS bottom row
    [75-PCB.sch]
2020-04-06 Assigned footprints
    [75-PCB.sch]
2020-04-07 Added switch for support for another bottom row layout
    [75-PCB.sch]
2020-04-07 Finished key layout in PCB file
    [75-PCB.sch]
2020-04-07 Finished PCB edges
    [75-PCB.kicad_pcb]
2020-04-07 Changed USB connector
    [75-PCB.kicad_pcb, 75-PCB.sch]
2020-04-14 Positioned underglow LEDs
    [75-PCB.kicad_pcb]
2020-04-15 Updated switch footprints
    [75-PCB.kicad_pcb, 75-PCB.sch]
2020-04-17 Finished MCU capacitor and USB traces
    [75-PCB.kicad_pcb]
2020-04-17 Placed LED resistors
    [75-PCB.kicad_pcb]
2020-04-17 Finished switch and LED matrix traces
    [75-PCB.kicad_pcb, 75-PCB.sch]
2020-04-18 Reset traces, changed component placement
    [75-PCB.kicad_pcb]
2020-04-18 Finished USB and 5V traces
    [75-PCB.kicad_pcb]
2020-04-18 Fixed underglow LED schematic and switch footprints
    [75-PCB.kicad_pcb, 75-PCB.sch]
2020-04-19 Finished row and LED ground traces
    [75-PCB.kicad_pcb, 75-PCB.sch]
2020-04-19 Finished column traces
    [75-PCB.kicad_pcb]
2020-04-19 Finished column and LED traces
    [75-PCB.kicad_pcb]
2020-04-19 Finished LED matrix
    [75-PCB.kicad_pcb]
2020-04-20 Created duplex matrix for switches and switched MCU to ATMega32U4
    [75-PCB.kicad_pcb, 75-PCB.sch]
2020-04-20 Finished USB and MCU traces
    [75-PCB.kicad_pcb]
2020-04-20 Finished column and row traces
    [75-PCB.kicad_pcb, 75-PCB.sch]
2020-04-21 Updated underglow LED placement
    [75-PCB.kicad_pcb]
2020-04-21 Changed underglow LED model
    [75-PCB.kicad_pcb, 75-PCB.sch]
2020-04-21 Finished routing traces around underglow LEDs
    [75-PCB.kicad_pcb]
2020-04-22 Added mounting holes
    [75-PCB.kicad_pcb, 75-PCB.sch]
2020-04-22 Finished traces and added ground fills
    [75-PCB.kicad_pcb, 75-PCB.sch]
2020-04-23 Adjusted silkscreen and added edge rails
    [75-PCB.kicad_pcb, 75-PCB.sch]
2020-04-23 Cleaned up schematic
    [75-PCB.kicad_pcb, 75-PCB.sch]
2020-04-24 Changed power trace width
    [75-PCB.kicad_pcb, 75-PCB.sch]
2020-04-24 Connected unconnected pad
    [75-PCB.kicad_pcb]
2020-04-24 Updated switch matrix
    [75-PCB.kicad_pcb, 75-PCB.sch]
2020-04-25 Added graphics
    [75-PCB.kicad_pcb, 75-PCB.sch]
2020-04-26 Renamed project
    [75-PCB-Hot-Swap.sch, Asok75.kicad_pcb, Asok75.sch]
2020-07-06 Added files for acrylic case
    [bottom.dxf, foot-0.dxf, foot-1.dxf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]
2020-07-08 Updated case files
    [bottom.dxf, foot0.dxf, foot1.dxf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]
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2020-08-03 Deleted traces, updated dimensions, added new symbols and footprints for side firing underglow LEDS
    [Asok75.sch, v1.kicad_pcb]
2020-08-04 Reorganised folders and placed RGB LEDs on hotswap pcb
    [Asok75hotswap.kicad_pcb, Asok75hotswap.sch, v1.kicad_pcb]
2020-08-11 Removed extra symbols in schematic in hotswap variant
    [Asok75.kicad_pcb, Asok75.sch, Asok75hotswap.kicad_pcb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]
2020-08-12 Updated PCB dimensions and component placement on hotswap variant
    [Asok75hotswap.kicad_pcb]
2020-08-14 Updated underglow LED footprint
    [Asok75hotswap.kicad_pcb, Asok75hotswap.sch]
2020-08-17 Routed USB and MCU area for hotswap version
    [Asok75hotswap.kicad_pcb, Asok75hotswap.sch]
2020-08-18 Updated edge cuts
    [Asok75.kicad_pcb, Asok75hotswap.kicad_pcb, Asok75hotswap2.kicad_pcb]
2020-08-18 Realigned underglow LEDs
    [Asok75.kicad_pcb]
2020-08-18 Updated hotswap PCB
    [Asok75.kicad_pcb, Asok75hotswap.kicad_pcb, Asok75hotswap2.kicad_pcb]
2020-08-19 Completed routing rows, MCU and USB
    [Asok75hotswap.kicad_pcb]
2020-08-19 Finished routing columns in hotswap version
    [Asok75hotswap.kicad_pcb]
2020-08-20 Routed underglow LEDs
    [Asok75hotswap.kicad_pcb, Asok75hotswap.sch]
2020-08-20 Finished routing underglow LED power traces
    [Asok75hotswap.kicad_pcb, Asok75hotswap.sch]
2020-08-22 Finished routing hotswap version
    [Asok75hotswap.sch, Asok75hotswapdone1.kicad_pcb]
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2020-09-12 Moved case folder to be with v1 PCB
    [Asok75hotswapdone1.kicad_pcb, bottom.dxf, foot1.dxf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]
2020-09-21 Refactored project into separate repositories
    [Asok75.kicad_pcb, Asok75.sch, Asok75hotswap.kicad_pcb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]
